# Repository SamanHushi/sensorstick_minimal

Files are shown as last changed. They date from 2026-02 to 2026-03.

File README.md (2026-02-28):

# minimal-co2-pcb

> [!NOTE]
> This board has not been physically tested.

## Todo

- [ ] Integrate into case

## Build of Materials (BOM)

Interactive BOM: https://samanhushi.github.io/sensorstick_minimal/

- 1x [ESP32-C3 SuperMini](https://www.aliexpress.com/item/1005006599448997.html)
- 1x [USB A plug](https://www.lcsc.com/product-detail/usb-connectors_xkb-connection-u217-041n-4bv81_C319178.html/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)
- 1x [SCD40 CO2 sensor](https://de.aliexpress.com/item/1005002905505683.html)
- 1x [SGP40](https://www.mouser.de/ProductDetail/Sensirion/SGP40-D-R4?qs=yqaQSyyJnNgaRqiZfsbS1Q%3D%3D)
- 1x [SHT40](https://www.mouser.de/ProductDetail/Sensirion/SHT40-AD1B-R2?qs=zW32dvEIR3scTT6A4VuzaQ%3D%3D)
- 1x [Ambient Light Sensor](https://www.lcsc.com/product-detail/C504893.html?s_z=n_C504893)

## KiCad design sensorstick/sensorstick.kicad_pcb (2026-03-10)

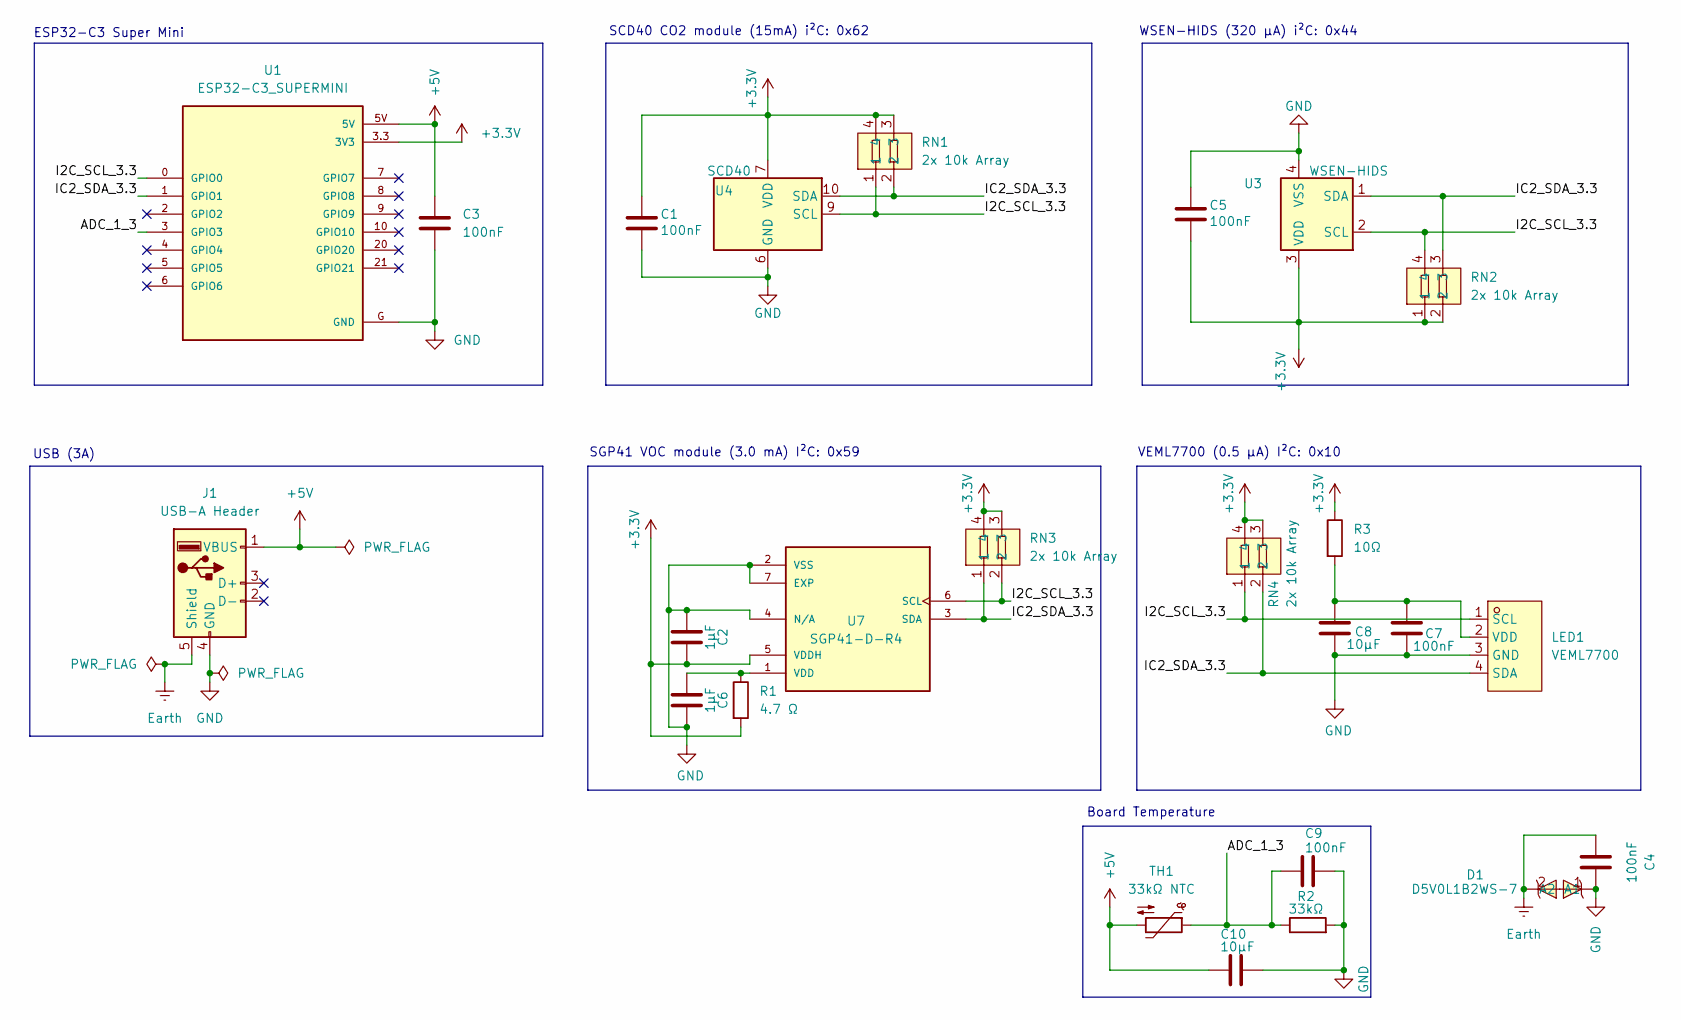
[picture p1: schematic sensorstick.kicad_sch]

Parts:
C1, C3, C4, C5, C7: 100nF; C_0603_1608Metric; partdb_id 573; LCSC C1591
C2, C6: 1μF; C_0603_1608Metric; partdb_id 428; LCSC C1591
C8: 10μF; C_0603_1608Metric; partdb_id 19; LCSC C1591
C9: 100nF; C_0603_1608Metric; partdb_id 573; LCSC C458914
C10: 10μF; C_0603_1608Metric; partdb_id 19; LCSC C458914
D1: D5V0L1B2WS-7; SOD-323_L1.8-W1.3-LS2.5-BI; partdb_id 429; LCSC Part C182013
J1: USB-A Header; USB-A-SMD_U217-041N-4BV81; partdb_id 248; LCSC Part C319178
LED1: VEML7700; LED-SMD_4P-L6.8-W2.4_VEML7700-TR; partdb_id 589; LCSC Part C504893
R1: 4.7 Ω; R_0603_1608Metric; partdb_id 330
R2: 33kΩ; R_0603_1608Metric; partdb_id 559
R3: 10Ω; R_0603_1608Metric; partdb_id 208
RN1, RN2, RN3, RN4: 2x 10k Array; RES-ARRAY-SMD_0402-4P-L1.0-W1.0-BL; partdb_id 431; LCSC Part C2765527
TH1: 33kΩ NTC; R_0603_1608Metric; partdb_id 571
U1: ESP32-C3_SUPERMINI; ESP32-C3_SUPERMINI_SMD; partdb_id 247
U3: WSEN-HIDS; Sensirion_DFN-4_1.5x1.5mm_P0.8mm_SHT4x_NoCentralPad; partdb_id 584
U4: SCD40; Sensirion_SCD4x-1EP_10.1x10.1mm_P1.25mm_EP4.8x4.8mm; partdb_id 566
U7: SGP41-D-R4; XDCR_SGP41-D-R4; PARTREV 1.0

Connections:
+3.3V: C1.2, C2.2, C5.1, R1.2, R3.1, RN1.3, RN1.4, RN2.1, RN2.2, RN3.3, RN3.4, RN4.3, RN4.4, U1.3.3 (3V3), U3.3 (VDD), U4.7 (VDD), U4.19 (VDD), U7.5 (VDDH)
+5V: C3.1, C10.1, J1.1 (VBUS), TH1.2, U1.5V
/ADC_1_3: C9.1, R2.1, TH1.1, U1.3 (GPIO3)
/I2C_SCL_3.3: LED1.1 (SCL), RN1.1, RN2.4, RN3.2, RN4.1, U1.0 (GPIO0), U3.2 (SCL), U4.9 (SCL), U7.6 (SCL)
/IC2_SDA_3.3: LED1.4 (SDA), RN1.2, RN2.3, RN3.1, RN4.2, U1.1 (GPIO1), U3.1 (SDA), U4.10 (SDA), U7.3 (SDA)
Earth: C4.1, D1.2 (A1), J1.5 (Shield), J1.6 (Shield)
GND: C1.1, C2.1, C3.2, C4.2, C5.2, C6.2, C7.2, C8.2, C9.2, C10.2, D1.1 (A2), J1.4 (GND), LED1.3 (GND), R2.2, U1.G (GND), U3.4 (VSS), U4.6 (GND), U4.20 (GND), U4.21 (GND), U7.2 (VSS), U7.4 (N/A), U7.7 (EXP)
unnamed: C7.1, C8.1, LED1.2 (VDD), R3.2
unnamed: C6.1, R1.1, U7.1 (VDD)

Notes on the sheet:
SCD40 CO2 module (15mA) i²C: 0x62
SGP41 VOC module (3.0 mA) I²C: 0x59
Board Temperature
ESP32-C3 Super Mini
WSEN-HIDS (320 μA) i²C: 0x44
USB (3A)
VEML7700 (0.5 μA) I²C: 0x10

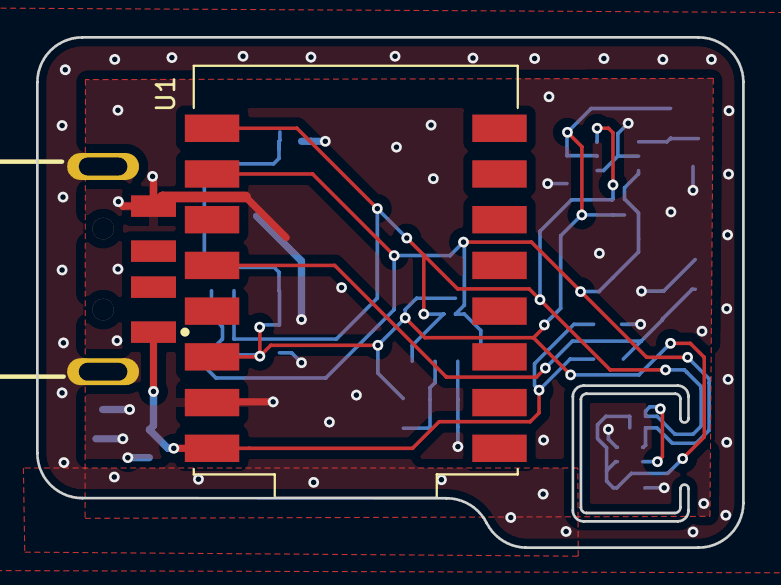
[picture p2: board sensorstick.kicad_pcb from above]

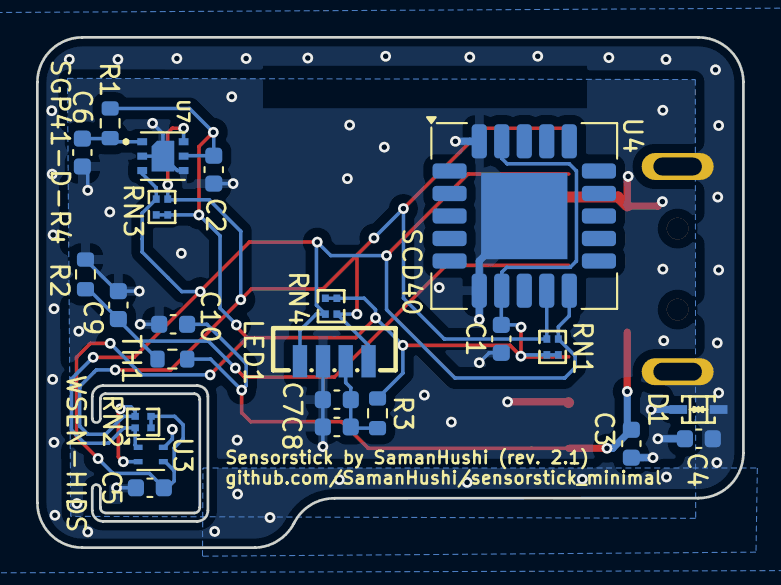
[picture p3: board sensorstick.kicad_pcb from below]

Board: 4 copper layers, 39.2 x 28.4 mm, 25 parts (23 on the bottom side), 9 nets.

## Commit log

2025-02-27 init project
    [minimal_CO2_board.kicad_pcb, minimal_CO2_board.kicad_sch]
2025-02-28 add BOM in README
2025-02-28 move into sub folder
    [minimal_CO2_board.kicad_pcb, minimal_CO2_board.kicad_sch]
2025-02-28 add battery
    [minimal_CO2_board.kicad_pcb, minimal_CO2_board.kicad_sch]
2025-02-28 add stuff
    [minimal_CO2_board.kicad_pcb, minimal_CO2_board.kicad_sch]
2025-02-28 change location of models
    [minimal_CO2_board.kicad_pcb]
2025-02-28 rename board
    [sensorstick.kicad_pcb, sensorstick.kicad_sch]
2025-02-28 fix pins
    [sensorstick.kicad_pcb, sensorstick.kicad_sch]
2025-03-01 add scd40 module
    [sensorstick.kicad_pcb]
2025-03-15 add condensator
    [sensorstick.kicad_pcb, sensorstick.kicad_sch]
2025-03-16 change filter
2025-03-16 updating routing
    [sensorstick.kicad_pcb]
2025-03-16 GitHub action to build Pages
    add Makefile
    add help
    change URL
    move text
    add InteractiveHtmlBom
    test
    use python 3.12
    add InteractiveHtmlBom
    remove
    add wxpython
    add libgtk-3-dev
    sudo
    libgtk-3-dev
    split
    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
    [sensorstick.kicad_pcb]
2025-03-16 set LCSC #
    [sensorstick.kicad_pcb, sensorstick.kicad_sch]
2025-03-17 update filter
    [sensorstick.kicad_pcb, sensorstick.kicad_sch]
2025-03-17 Add standoff mounting holes to display footprint
2025-03-17 update footprints
    [sensorstick.kicad_pcb]
2025-03-18 add 2 holes
2025-03-18 set value
    [sensorstick.kicad_pcb, sensorstick.kicad_sch]
2025-03-21 round edges
    [sensorstick.kicad_pcb]
2025-03-27 Marek did things
    [sensorstick.kicad_pcb, sensorstick.kicad_sch]
2025-03-27 move schematic arround & label name
    [sensorstick.kicad_pcb, sensorstick.kicad_sch]
2025-03-27 link LCSC parts
    [sensorstick.kicad_pcb]
2025-03-27 add gerber files
2025-03-27 update org
    [BOM-sensorstick.csv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]
2025-03-27 OLED: add front cortyard
    [sensorstick.kicad_pcb]
2025-03-27 add cortyard
    [sensorstick.kicad_pcb]
2025-03-27 move OLED
    [sensorstick.kicad_pcb]
2025-04-18 cleanup LCSC part ID's
    [sensorstick.kicad_pcb, sensorstick.kicad_sch]
2025-07-07 add GY-SGP30 symbol & footprint
2025-07-07 new sensor possition
    [sensorstick.kicad_pcb, sensorstick.kicad_sch]
2025-07-07 update gitignore
    [BOM-sensorstick.csv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]
2025-07-07 added traceing
    [sensorstick.kicad_pcb]
2025-07-07 changed esp possition
    [sensorstick.kicad_pcb]
2025-10-13 minimal desin with new sensor
    [sensorstick.kicad_pcb, sensorstick.kicad_sch]
2025-10-14 finished first routing, open for review
    [sensorstick.kicad_pcb, sensorstick.kicad_sch]
2025-11-26 moved all parts on the backside for easyer asambly
    [sensorstick.kicad_pcb, sensorstick.kicad_sch]
2025-11-26 added more vias
    [sensorstick.kicad_pcb]
2025-11-28 added jcsc part numbers
    [sensorstick.kicad_pcb, sensorstick.kicad_sch]
2026-01-14 changed 3,3 to 1,8 module and i2c level shifter
    [sensorstick.kicad_pcb, sensorstick.kicad_sch]
2026-01-17 changed rev number to 2
    [sensorstick.kicad_pcb, sensorstick.kicad_sch]
2026-01-23 added NTC for board Temperature and finaly touch bevore ordering the PCB
    [sensorstick.kicad_pcb, sensorstick.kicad_sch]
2026-01-23 changed ntc values
    [sensorstick.kicad_sch]
2026-01-27 changed sgp30 to sgp
    [sensorstick.kicad_pcb, sensorstick.kicad_sch]
2026-01-27 added VEML7700
    because of moving from SGP30 to SGP41 I got rid of everything handling 1.8V and 1.8V I²C with space on the pcb I now filled with a High Accuracy Ambient Light Sensor
    [sensorstick.kicad_pcb, sensorstick.kicad_sch]
2026-01-27 final touch for ordeing it
    [sensorstick.kicad_pcb, sensorstick.kicad_sch]
2026-02-26 Revise BOM with updated components and links
    Updated the Build of Materials (BOM) section with new components and corrected links.
2026-02-28 Update BOM link in README.md
2026-03-02 build for jlcpcb including footprint values
2026-03-02 added partdb id to ci
    [sensorstick.kicad_sch]
2026-03-02 add partdb_id for part
    [sensorstick.kicad_pcb]
2026-03-10 added partdb ids
    [sensorstick.kicad_pcb, sensorstick.kicad_sch]
